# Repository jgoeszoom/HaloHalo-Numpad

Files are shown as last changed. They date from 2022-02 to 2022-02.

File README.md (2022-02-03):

# Halo-Halo Numpad!
A custom PCB implementation of a numpad that I designed for my girlfriend. 
(The name comes from a popular Filipino dessert; we thought it would be a fun name)

## Specifications
This numpad includes a 5x4 matrix of MX-style key switches along with a column of 
rotary encoders with a push-on switch built-in. 

At the moment, the board is still a WIP. The final board will include headers to attach a microcontroller that
will be chosen later. There should also be space for a small OLED/LCD screen. 

### To-do: 
	- [X] Choose a microcontroller to use
	- [X] Add headers for microcontroller chosen 
	- [] Update corresponding PDFs and images
	- [] Add space on PCB for the small screen

## Schematic

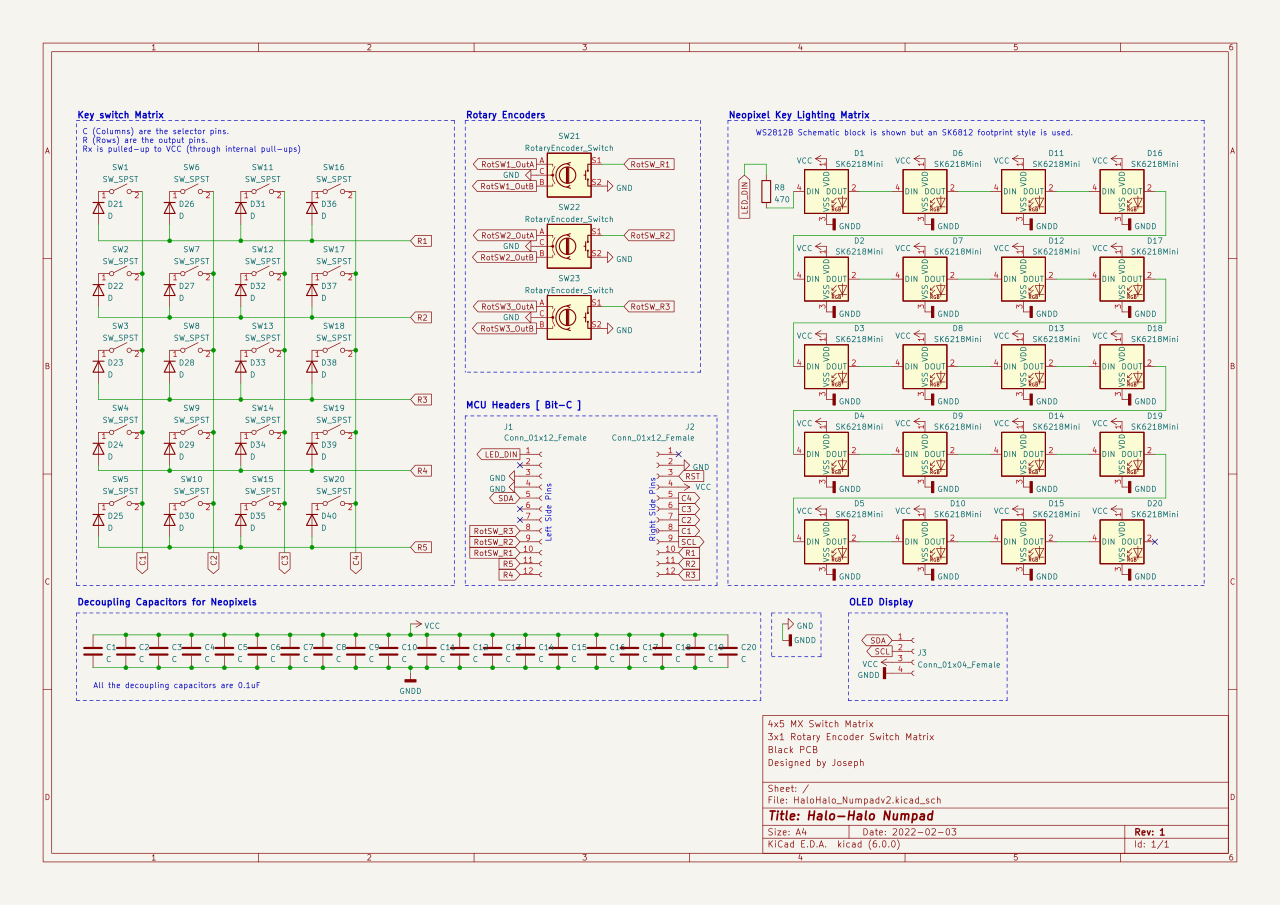
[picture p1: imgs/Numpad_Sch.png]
Schematic of Numpad


## PCB

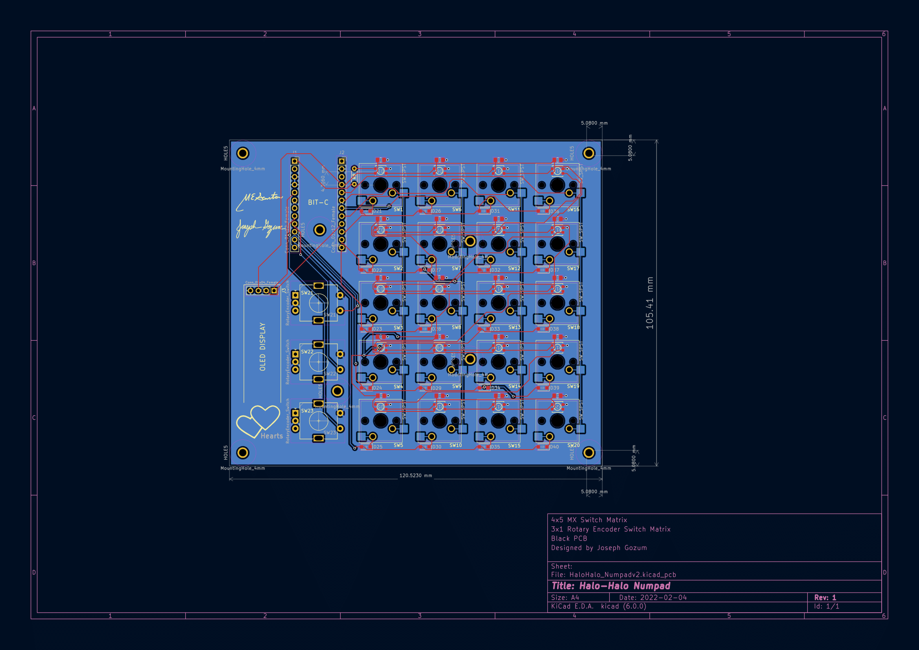
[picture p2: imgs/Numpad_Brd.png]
PCB of Numpad


## Render

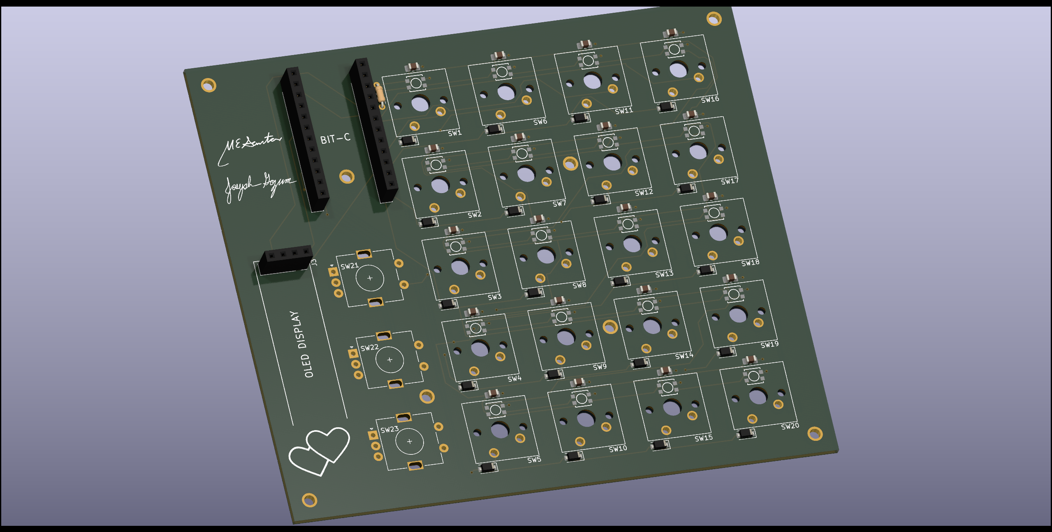
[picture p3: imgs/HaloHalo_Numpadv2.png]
Render of PCB


## Bill-of-Materials

| References | Value | Footprint | Quantity |
| --- | ----- | --- | --- |
| C1-C20 | 0.1uF | 0805 | 20 |
| R1-R7, R9  | 4.7k  | Axial DIN0204 | 8 |
| R8 | 470 | Axial DIN0204 | 1 |
| D1-D20 | N/A | SK6812 Mini | 20 | 
| D21-D40 | N/A | SOD-123F  | 20 |
| SW1-SW20 | N/A | Cherry MX | 20 |
| SW21-SW23  | Rotary| Alps EC11E| 3 |

C - Capacitors; R - Resistors; D - Diodes; SW - Switches

Included in the BOM directory is an HTML for an interactive BOM generated by a plugin in KiCAD. 
When this is opened, a rendered HTML page shows all the items on the PCB as well as their location
and values and footprints. It's a nice side by side view of a BOM and the PCB.

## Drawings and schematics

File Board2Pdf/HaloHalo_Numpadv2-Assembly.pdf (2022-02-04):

# 5.0800 mm 5.0800 mm 5.0800 mm

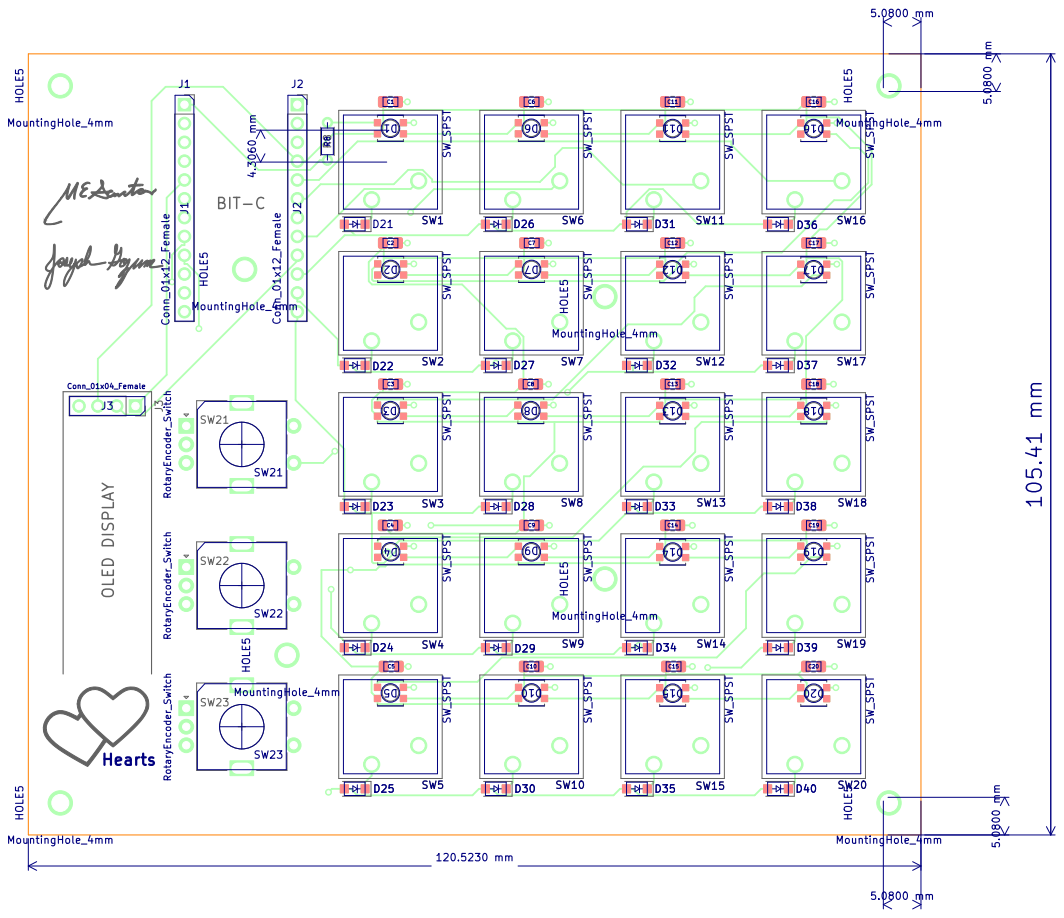
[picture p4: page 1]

3x1 Rotary Encoder Switch Matrix 4x5 MX Switch Matrix

Black PCB
Designed by Joseph Gozum

Sheet: Assembly
File: HaloHalo_Numpadv2.kicad_pcb
Id: 1/1 Title: Halo-Halo Numpad

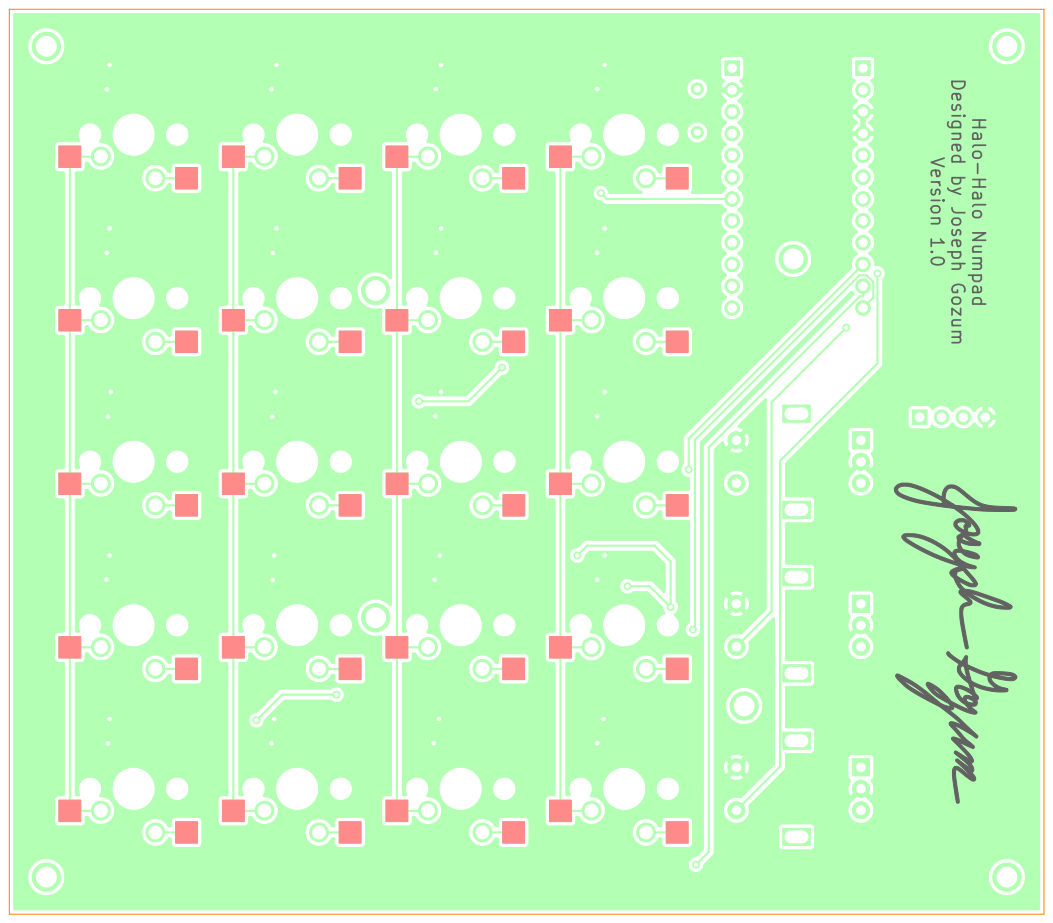
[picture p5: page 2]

Halo-Halo Numpad Designed by Joseph Gozum Version 1.0 1 2 3 4 5 6 1 2 3 4 5 6 ABCD ABCD Date: 2022-01-30 KiCad E.D.A. kicad (6.0.0) Size: A4 Rev: 1

3x1 Rotary Encoder Switch Matrix 4x5 MX Switch Matrix

Black PCB
Designed by Joseph Gozum

Sheet: Assembly
File: HaloHalo_Numpadv2.kicad_pcb
Id: 1/1 Title: Halo-Halo Numpad

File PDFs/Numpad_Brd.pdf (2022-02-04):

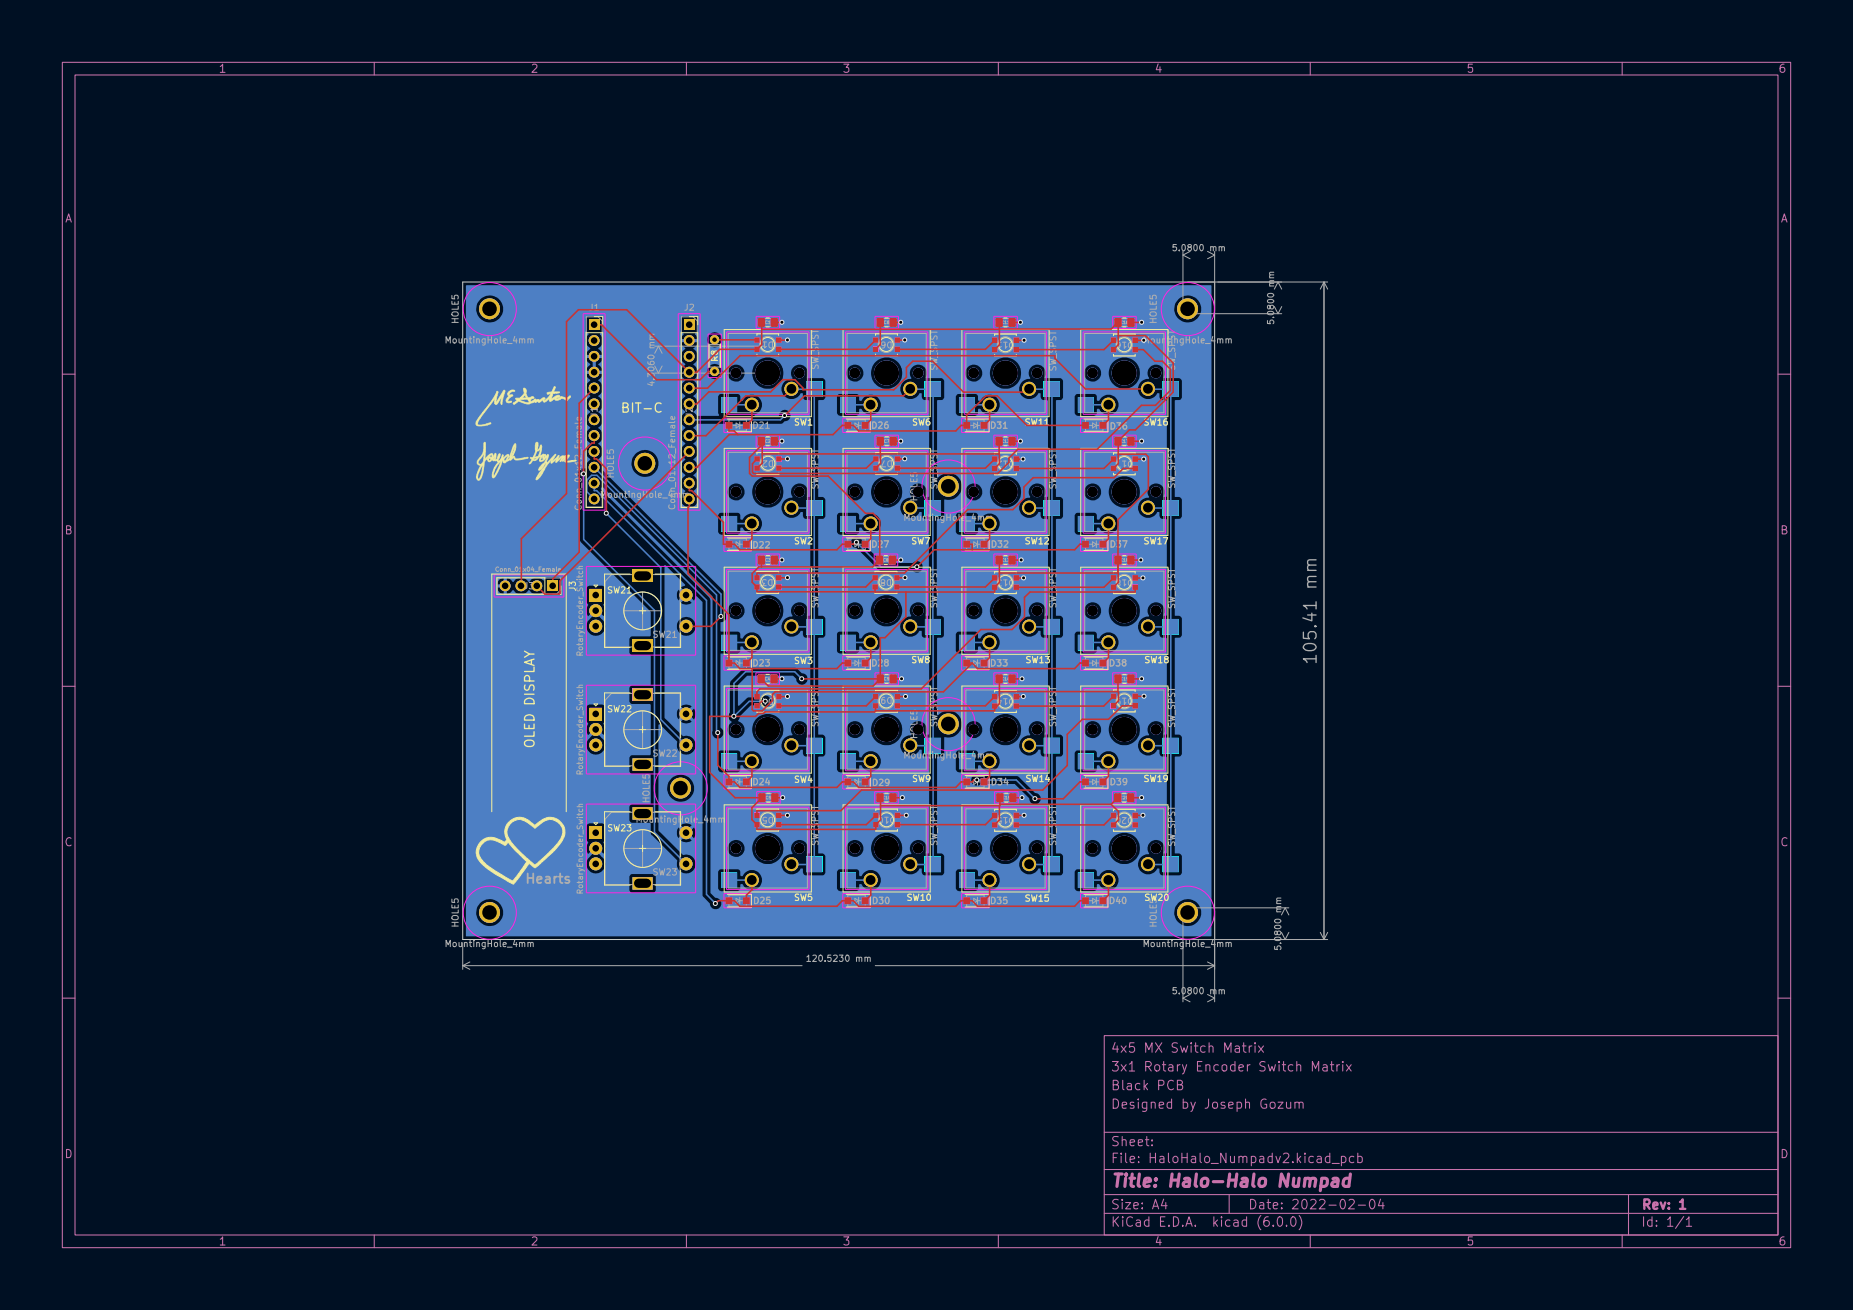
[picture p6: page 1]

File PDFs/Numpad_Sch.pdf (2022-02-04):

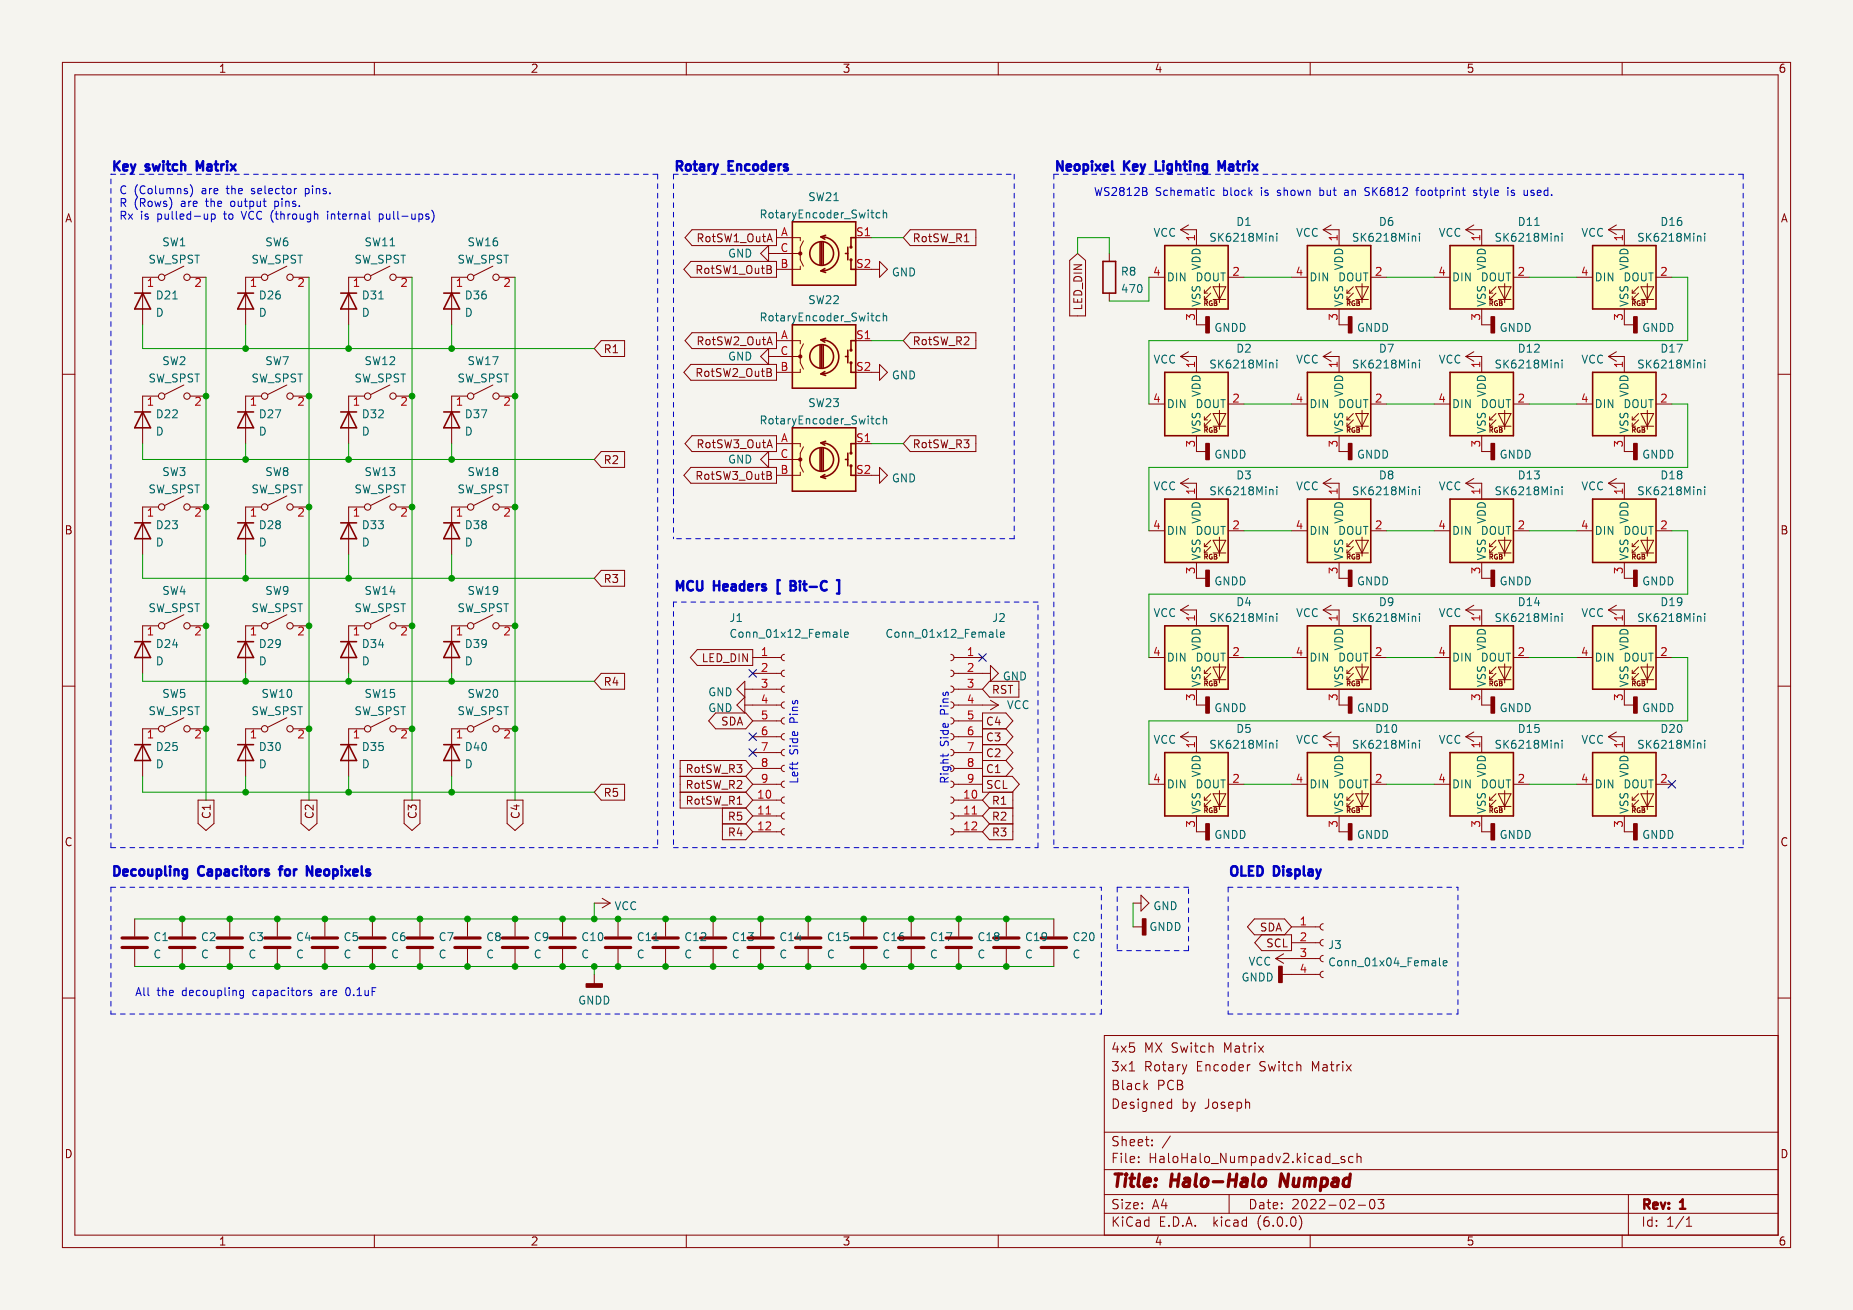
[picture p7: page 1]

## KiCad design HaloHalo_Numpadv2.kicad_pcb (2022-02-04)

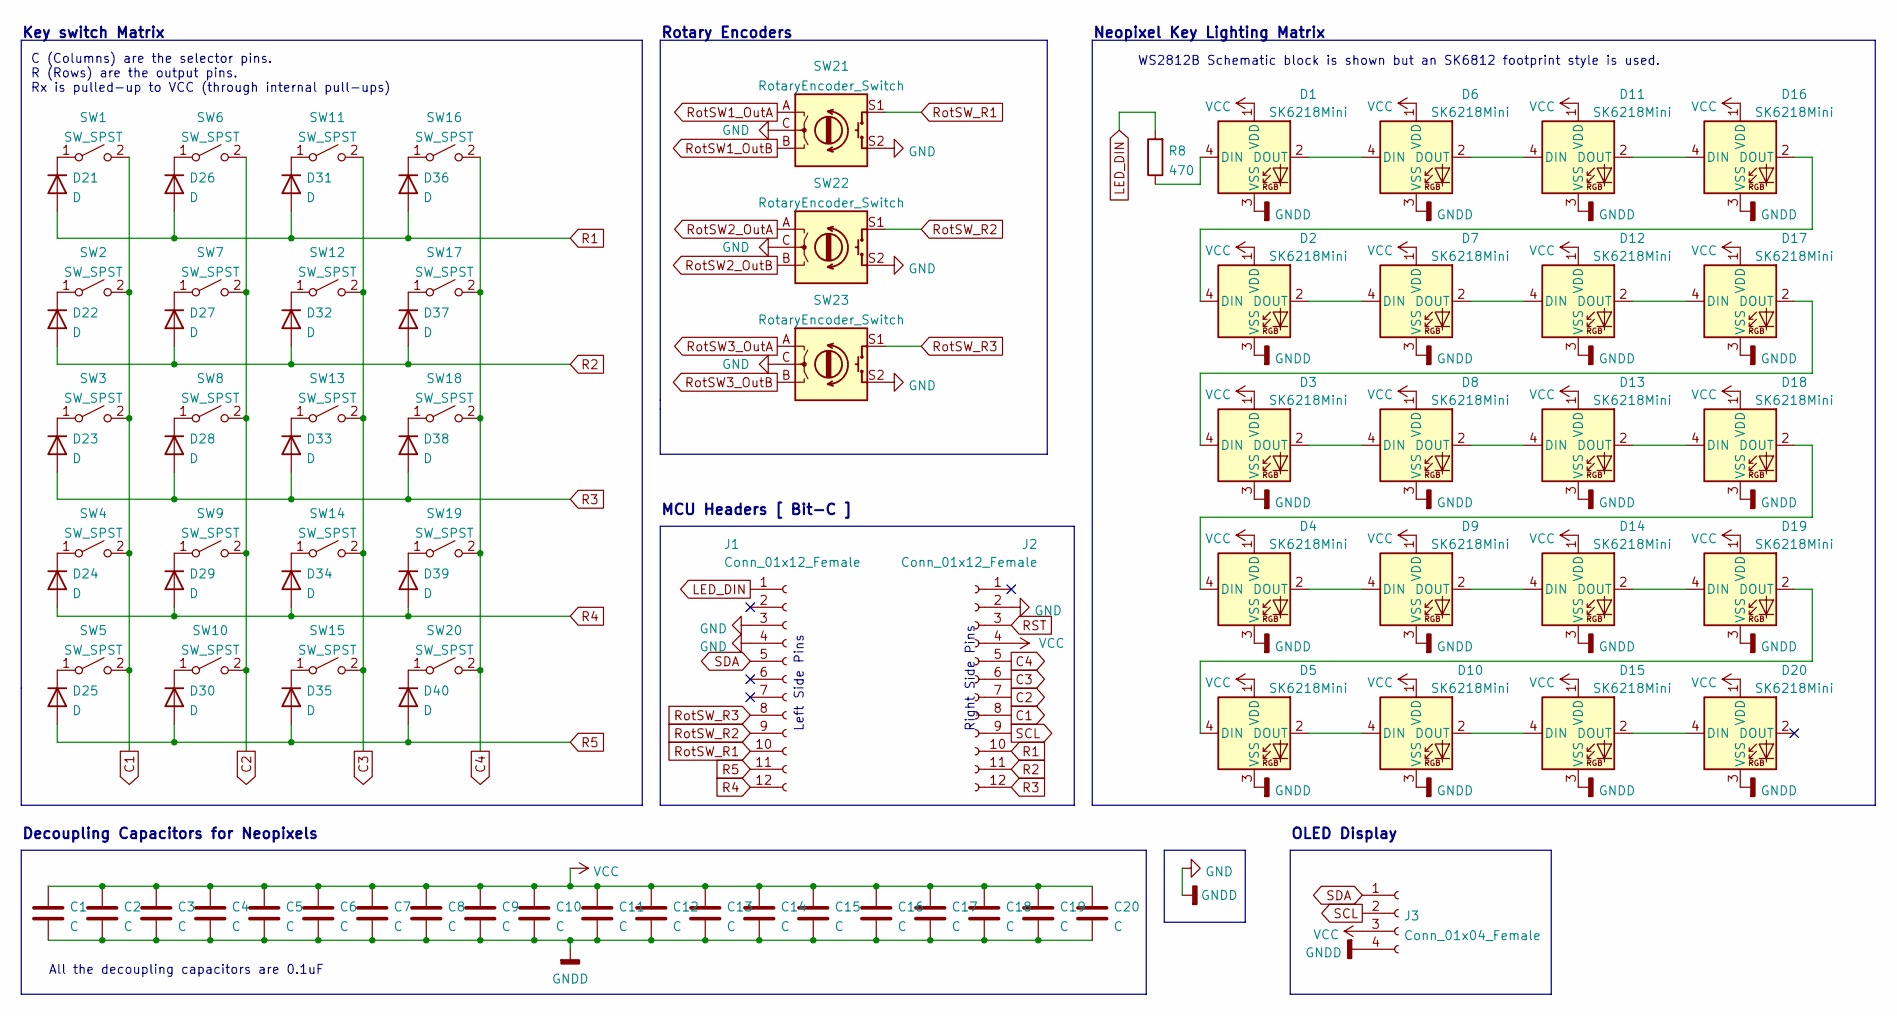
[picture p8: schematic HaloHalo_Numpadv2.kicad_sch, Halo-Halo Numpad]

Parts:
C1: C; C_0805_2012Metric_Pad1.18x1.45mm_HandSolder; MFR. Part Number FS055C104K4Z2A; LCSC Part Number C444732
C2, C3, C4, C5, C6, C7, C8, C9, C10, C11, C12, C13, C14, C15, C16, C17, C18, C19, C20: C; C_0805_2012Metric_Pad1.18x1.45mm_HandSolder
D1, D2, D3, D4, D5, D6, D7, D8, D9, D10, D11, D12, D13, D14, D15, D16, D17, D18, D19, D20: SK6218Mini; SK6812Mini
D21, D22, D23, D24, D25, D26, D27, D28, D29, D30, D31, D32, D33, D34, D35, D36, D37, D38, D39, D40: D; D_SOD-123F; MFR. Part Number SM4007PL; LCSC Part Number C64898
J1, J2: Conn_01x12_Female; PinSocket_1x12_P2.54mm_Vertical
J3: Conn_01x04_Female; PinSocket_1x04_P2.54mm_Vertical
R8: 470; R_Axial_DIN0204_L3.6mm_D1.6mm_P5.08mm_Horizontal
SW1, SW2, SW3, SW4, SW5, SW6, SW7, SW8, SW9, SW10, SW11, SW12, SW13, SW14, SW15, SW16, SW17, SW18, SW19, SW20: SW_SPST; SW_Cherry_MX_1.00u_PCB
SW21, SW22, SW23: RotaryEncoder_Switch; RotaryEncoder_Alps_EC11E-Switch_Vertical_H20mm

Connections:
C1: J2.8, SW1.2 (B), SW2.2 (B), SW3.2 (B), SW4.2 (B), SW5.2 (B)
C2: J2.7, SW6.2 (B), SW7.2 (B), SW8.2 (B), SW9.2 (B), SW10.2 (B)
C3: J2.6, SW11.2 (B), SW12.2 (B), SW13.2 (B), SW14.2 (B), SW15.2 (B)
C4: J2.5, SW16.2 (B), SW17.2 (B), SW18.2 (B), SW19.2 (B), SW20.2 (B)
GND: C1.2, C2.2, C3.2, C4.2, C5.2, C6.2, C7.2, C8.2, C9.2, C10.2, C11.2, C12.2, C13.2, C14.2, C15.2, C16.2, C17.2, C18.2, C19.2, C20.2, D1.3 (VSS), D2.3 (VSS), D3.3 (VSS), D4.3 (VSS), D5.3 (VSS), D6.3 (VSS), D7.3 (VSS), D8.3 (VSS), D9.3 (VSS), D10.3 (VSS), D11.3 (VSS), D12.3 (VSS), D13.3 (VSS), D14.3 (VSS), D15.3 (VSS), D16.3 (VSS), D17.3 (VSS), D18.3 (VSS), D19.3 (VSS), D20.3 (VSS), J1.3, J1.4, J2.2, J3.4, SW21.C, SW21.S2, SW22.C, SW22.S2, SW23.C, SW23.S2
LED_DIN: J1.1, R8.2
unnamed: D1.2 (DOUT), D6.4 (DIN)
unnamed: D1.4 (DIN), R8.1
unnamed: D2.2 (DOUT), D7.4 (DIN)
unnamed: D3.2 (DOUT), D8.4 (DIN)
unnamed: D4.2 (DOUT), D9.4 (DIN)
unnamed: D10.2 (DOUT), D15.4 (DIN)
unnamed: D5.2 (DOUT), D10.4 (DIN)
unnamed: D11.2 (DOUT), D16.4 (DIN)
unnamed: D6.2 (DOUT), D11.4 (DIN)
unnamed: D12.2 (DOUT), D17.4 (DIN)
unnamed: D7.2 (DOUT), D12.4 (DIN)
unnamed: D13.2 (DOUT), D18.4 (DIN)
unnamed: D8.2 (DOUT), D13.4 (DIN)
unnamed: D14.2 (DOUT), D19.4 (DIN)
unnamed: D9.2 (DOUT), D14.4 (DIN)
unnamed: D15.2 (DOUT), D20.4 (DIN)
unnamed: D2.4 (DIN), D16.2 (DOUT)
unnamed: D3.4 (DIN), D17.2 (DOUT)
unnamed: D4.4 (DIN), D18.2 (DOUT)
unnamed: D5.4 (DIN), D19.2 (DOUT)
unnamed: D21.1 (K), SW1.1 (A)
unnamed: D22.1 (K), SW2.1 (A)
unnamed: D23.1 (K), SW3.1 (A)
unnamed: D24.1 (K), SW4.1 (A)
unnamed: D25.1 (K), SW5.1 (A)
unnamed: D26.1 (K), SW6.1 (A)
unnamed: D27.1 (K), SW7.1 (A)
unnamed: D28.1 (K), SW8.1 (A)
unnamed: D29.1 (K), SW9.1 (A)
unnamed: D30.1 (K), SW10.1 (A)
unnamed: D31.1 (K), SW11.1 (A)
unnamed: D32.1 (K), SW12.1 (A)
unnamed: D33.1 (K), SW13.1 (A)
unnamed: D34.1 (K), SW14.1 (A)
unnamed: D35.1 (K), SW15.1 (A)
unnamed: D36.1 (K), SW16.1 (A)
unnamed: D37.1 (K), SW17.1 (A)
unnamed: D38.1 (K), SW18.1 (A)
unnamed: D39.1 (K), SW19.1 (A)
unnamed: D40.1 (K), SW20.1 (A)
R1: D21.2 (A), D26.2 (A), D31.2 (A), D36.2 (A), J2.10
R2: D22.2 (A), D27.2 (A), D32.2 (A), D37.2 (A), J2.11
R3: D23.2 (A), D28.2 (A), D33.2 (A), D38.2 (A), J2.12
R4: D24.2 (A), D29.2 (A), D34.2 (A), D39.2 (A), J1.12
R5: D25.2 (A), D30.2 (A), D35.2 (A), D40.2 (A), J1.11
RST: J2.3
RotSW1_OutA: SW21.A
RotSW1_OutB: SW21.B
RotSW2_OutA: SW22.A
RotSW2_OutB: SW22.B
RotSW3_OutA: SW23.A
RotSW3_OutB: SW23.B
RotSW_R1: J1.10, SW21.S1
RotSW_R2: J1.9, SW22.S1
RotSW_R3: J1.8, SW23.S1
SCL: J2.9, J3.2
SDA: J1.5, J3.1
VCC: C1.1, C2.1, C3.1, C4.1, C5.1, C6.1, C7.1, C8.1, C9.1, C10.1, C11.1, C12.1, C13.1, C14.1, C15.1, C16.1, C17.1, C18.1, C19.1, C20.1, D1.1 (VDD), D2.1 (VDD), D3.1 (VDD), D4.1 (VDD), D5.1 (VDD), D6.1 (VDD), D7.1 (VDD), D8.1 (VDD), D9.1 (VDD), D10.1 (VDD), D11.1 (VDD), D12.1 (VDD), D13.1 (VDD), D14.1 (VDD), D15.1 (VDD), D16.1 (VDD), D17.1 (VDD), D18.1 (VDD), D19.1 (VDD), D20.1 (VDD), J2.4, J3.3

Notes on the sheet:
Left Side Pins
Key switch Matrix
MCU Headers [ Bit-C ]
Right Side Pins
Rotary Encoders
WS2812B Schematic block is shown but an SK6812 footprint style is used.
OLED Display
C (Columns) are the selector pins. R (Rows) are the output pins. Rx is pulled-up to VCC (through internal pull-ups)
Neopixel Key Lighting Matrix
All the decoupling capacitors are 0.1uF
Decoupling Capacitors for Neopixels

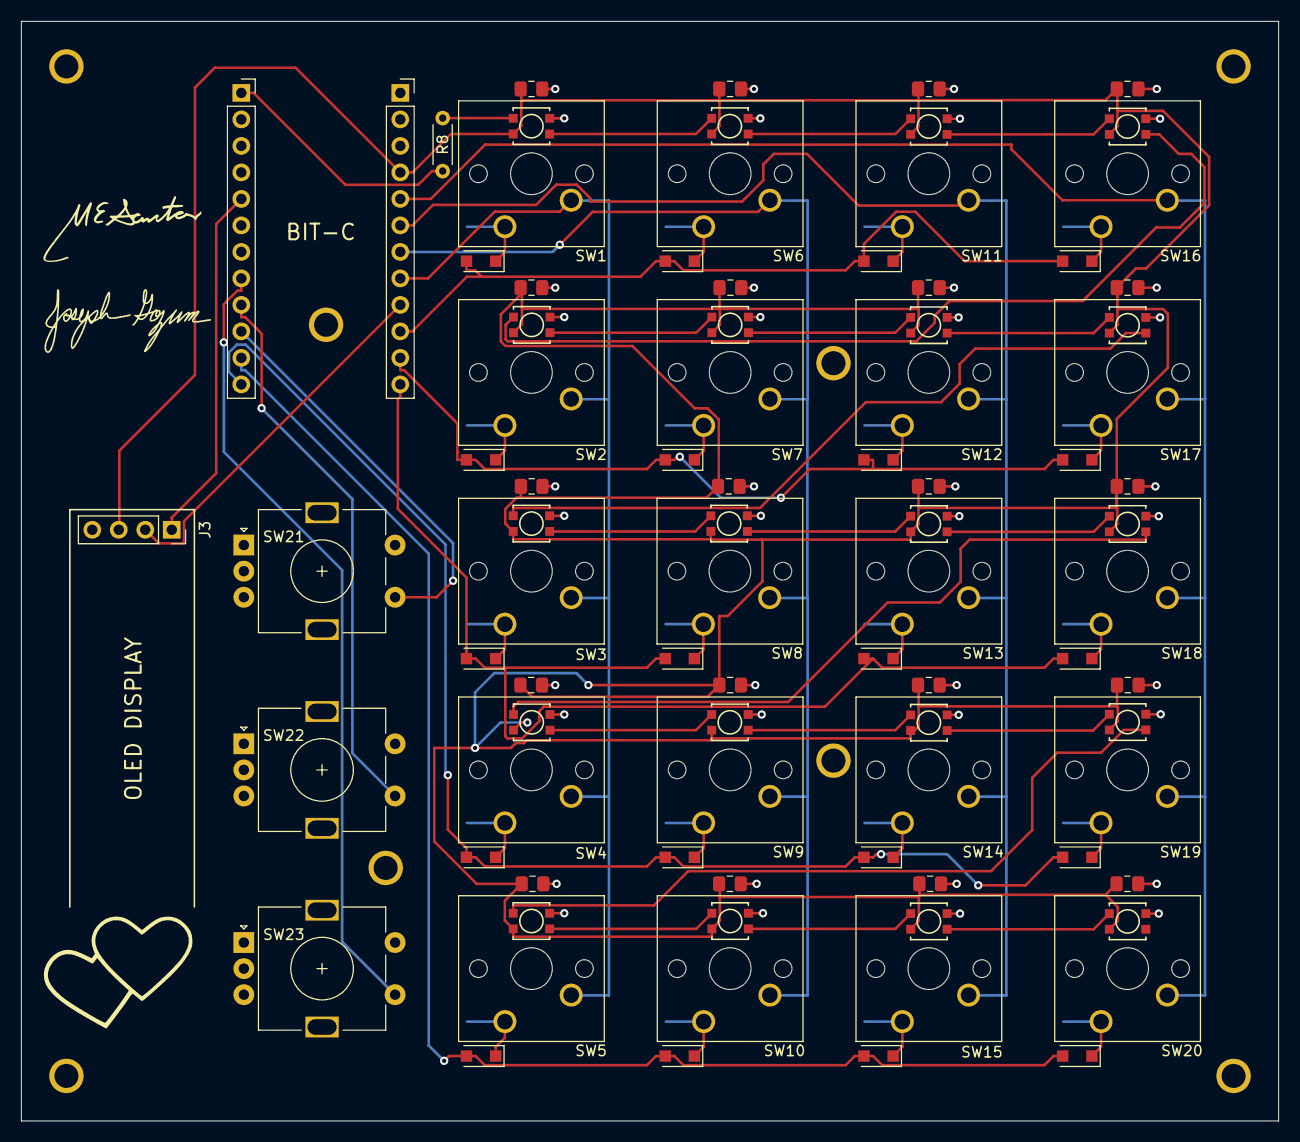
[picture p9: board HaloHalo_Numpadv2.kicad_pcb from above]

Board: 2 copper layers, 120.5 x 105.4 mm, 99 parts (0 on the bottom side), 57 nets.

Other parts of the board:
G1, G2, G3: LOGO
HOLE5, HOLE5#2, HOLE5#3, HOLE5#4, HOLE5#5, HOLE5#6, HOLE5#7, HOLE5#8: MountingHole_4mm; MountingHole_M2
Hearts: LOGO

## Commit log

2022-01-30 Changed colors of PCB assembly files in Board2Pdf. Placed all diodes on PCB.
    [HaloHalo_Numpadv2.kicad_pcb]
2022-01-30 Flipped orientation of key switches. Began initial trace routing.
    [HaloHalo_Numpadv2.dsn, HaloHalo_Numpadv2.kicad_pcb]
2022-01-30 Updated schematic fields. Uploaded PDFs and images of schematic.
    [HaloHalo_Numpadv2.kicad_sch]
2022-01-30 Added PCB PDFs and images
    [HaloHalo_Numpadv2.kicad_pcb]
2022-01-30 Added PCB Board PDF and png
    [HaloHalo_Numpadv2.kicad_pcb]
2022-01-30 Added PCB image to README
2022-01-30 Fixed image link in README for PCB section
2022-01-30 Added PCB render image
2022-01-30 Added Rendered PCB image to README.
2022-01-31 Added interactive BOM HTML and BOM section in READ
2022-01-31 Added BOM section to README. Link to interactive BOM
2022-01-31 Fixed link to BOM in README
2022-01-31 Attempt #2 to fix BOM link in README
2022-01-31 Removed link to HTML in BOM section of README. Just described what it is instead.
2022-02-02 Start ignorning SVGs and updated PDF and PNG of Numpad Schematic
    [HaloHalo_Numpadv2.kicad_sch]
2022-02-02 Fixed wiring of active low switch matrix in Eschema. Updated corresponding PNG and PDF file for schematic.
    [HaloHalo_Numpadv2.kicad_sch]
2022-02-03 Updated Schematic and PCB to include headers for OLED display. Need to update corresponding PDFs and images.
    [HaloHalo_Numpadv2.dsn, HaloHalo_Numpadv2.kicad_pcb, HaloHalo_Numpadv2.kicad_sch]
2022-02-04 Added OLED display headers
    [HaloHalo_Numpadv2.dsn, HaloHalo_Numpadv2.kicad_pcb, HaloHalo_Numpadv2.kicad_sch]
2022-02-04 Added silkscreen images to PCB
    [HaloHalo_Numpadv2.kicad_pcb]
2022-02-04 Updated all image files and PDFs
    [HaloHalo_Numpadv2.kicad_pcb, HaloHalo_Numpadv2.kicad_sch]
2022-02-04 Moved position of display headers in PCB. Started tracking gerbers.zip
    [HaloHalo_Numpadv2.kicad_pcb]
